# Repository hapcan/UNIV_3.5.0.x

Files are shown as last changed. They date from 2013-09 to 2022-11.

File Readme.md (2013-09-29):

UNIV 3.5.0.x
============

IR Tx/Rx MODULE - infrared transmitter/receiver

Device webpage: http://hapcan.com/devices/universal/univ_3/univ_3-5-0-x/

Hardware created in Eagle PCB Software http://www.cadsoftusa.com/

Firmware created in Microchip MPLAB http://www.microchip.com/mplabide/ in assembly language

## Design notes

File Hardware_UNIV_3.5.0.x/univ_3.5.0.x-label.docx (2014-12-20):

+5V GND IRRX IRTX ODB. I NADAJNIK PODCZERWIENI TYP UNIV 3.5.0.x S/N 0000055Bh | +5V GND IRRX IRTX INFRARED RCVR/TRNSMTR TYPE UNIV 3.5.0.x S/N 0000055Bh

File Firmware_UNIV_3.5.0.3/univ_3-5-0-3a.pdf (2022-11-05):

# INFRARED RECEIVER / TRANSMITTER FIRMWARE

# UNIV 3.5.0.3

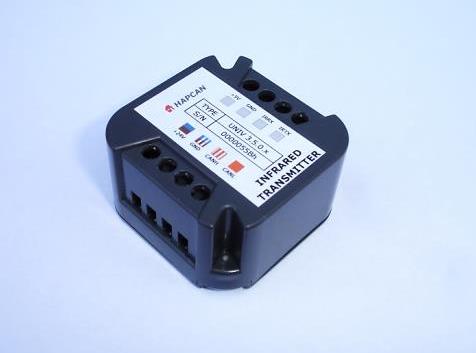
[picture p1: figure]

© 2014 hapcan.com | univ_3-5-0-3a.pdf - page 1 / 6

### 1. Features

- Firmware for Infrared Receiver/Transmitter UNIV 3.5.0.x.

- Receives and recognizes infrared codes - Sony SIRC 12 bit (32 addresses, 127 commands) – 4k codes - Sony SIRC 15 bit (256 addresses, 127 commands) – 32k codes - Sony SIRC 20 bit (8192 addresses, 127 commands) – 1M codes - Philips RC5 (32 addresses, 127 commands) – 4k codes - NEC 16 bit (256 addresses, 256 commands) – 65k codes - NEC 24 bit (65280 addresses, 256 commands) – 16M codes - Emits above codes - Learns IR codes from original remotes which have carrier frequency between 27 – 49kHz and maximum 335 bits length - Emits any IR codes with carrier frequency 18 - 500kHz - It has memory for 100 IR learnt or converted from Pronto format codes - Allows defining up to 128 CAN messages which can indirectly control the module - Transmit (42 messages) and receive (42 messages) FIFO buffers

### 2. Compatibility - Firmware for UNIV 3.5.0.x module - Firmware can be uploaded into processor with bootloader version 3.1 or

compatible.
- In current firmware version the learnt IR codes must end with a value of 00, so codes scanned in previous versions are not compatible. Please re-scan codes or edit them and the last 7F value replace with 00.

### 3. Firmware version

UNIV | 3 | . | 5 | . | 0 | . | 3

### firmware version application version application type (infrared receiver / transmitter) processor version universal processor

### 4. Communication Frames (messages)

### 4.1. Infrared Receiver frame

The module sends information of received infrared code, and another message when infrared transmission stops.

### Table 1. INFRARED RECEIVER frame – beginning of receiving the code

Frame type | Flags | Module | Group | D0 | D1 | D2 | D3 | D4 | D5 | D6 | D7
0x303 | 3 | 2 | 1 | 0 | Node Nr | Group Nr | 0xFF | 0xFF | CODE TYPE | CODE1 | CODE2 | CODE3 | 0xFF | 0xFF
0x302 | – universal module frame, relay
3 | - | - not used flag, read as “0”
2 | - | - not used flag, read as “0”
1 | - | - not used flag, read as “0”
0 | RE | - response flag, flag is equal “1” if node was requested. If flag is equal „0” it means that status of output has just changed.
Node Nr | - message sender node number
Group Nr | - message sender group number
CODE TYPE | 0x03 - received SIRC 12 bit code (32 addresses, 127
| | commands), CODE1=address, CODE2=command, CODE3=0xFF
| | 0x04 - received SIRC 15 bit code (256 addresses, 127 commands), CODE1=address, CODE2=command, CODE3=0xFF
| | 0x05 - received SIRC 20 bit code (8192 addresses, 127 commands),
| | CODE1=address MSB, CODE2=address LSB, CODE3=command 0x06- received RC5 code (32 addresses, 127 commands), CODE1=address, CODE2=command, CODE3=0xFF
| | 0x07- received NEC 16 bit code (256 addresses, 256 commands),
| | CODE1=address, CODE2=command, CODE3=0xFF 0x08 - received NEC 24 bit code, (65280 addresses, 256 commands)
| | CODE1=address MSB, CODE2=address LSB, CODE3=command

## UNIV 3.5.0.3

When transmission of infrared signal stops, the module sends another message. The difference between message at the beginning and at the end of transmission is in a D2 byte.

### Table 2. INFRARED RECEIVER frame – end of the IR transmission

Frame type | Flags | Module | Group | D0 | D1 | D2 | D3 | D4 | D5 | D6 | D7
0x303 | 0x1 | Node Nr | Group Nr | 0xFF | 0xFF | CODE TYPE +0x80 | CODE1 | CODE2 | CODE3 | 0xFF | 0xFF

### 4.2. Learning IR codes

The module enables learning and saving infrared codes into memory. Scanning should be performed in two steps: scanning the carrier frequency signal and then scanning the signal content. The current version of the HAPCAN Programmer scans only the content of the signal and assigns the default 38kHz carrier frequency.

After receiving instructions "Learn code - the carrier frequency of the transmitted IR signal from the remote controller” (control instructions) and correct receiving IR code, the module sends carrier frequency frame. If the

### module does not receive the IR code, then sends the error frame (Table 5)

### Table 3. LEARNT IR SIGNAL CARRIER FREQUENCY frame

Frame type | Flags | Module | Group | D0 | D1 | D2 | D3 | D4 | D5 | D6 | D7
0x303 | 0x1 | Node Nr | Group Nr | 0x00 | CARRIER | 0xFF | 0xFF | 0xFF | 0xFF | 0xFF | 0xFF
0x3031 | – universal module, infrared receiver frame
Node Nr | - message sender node number
Group Nr | - message sender group number
0x00 | - frame data type (0x00 – IR carrier frequency frame)
CARRIER | - received frequency codded: f = 4608/(CARRIER+1) [kHz]

After receiving instructions "Learn code - the body of transmitted IR signal from the remote controller” (control instructions) and correct receiving IR code, the module sends 96 frames containing IR signal body. If there is any

### problem with code learning, the module sends error frame (Table 5)

### Table 4. LEARNT IR SIGNAL CODE frames

Frame type | Flags | Module | Group | D0 | D1 | D2 | D3 | D4 | D5 | D6 | D7
0x303 | 0x1 | Node Nr | Group Nr | FRAME No | CODE0 | CODE1 | CODE2 | CODE3 | CODE4 | CODE5 | CODE6
0x3031 | – universal module, infrared receiver frame
Node Nr | - message sender node number
Group Nr | - message sender group number
FRAME No | - number of frame with IR code (1-96)
CODE0 | - IR signal carrier frequency taken from IR signal carrier frequency frame (Table 1)
CODE1-672 | - data of received IR (671 bytes sent in 96 frames)
Bit <7> of each byte defines if this is IR burst (bit <7> = „1”) or space (bit <7> = „0”) in IR code
The length of the burst or space is equal: 40us * byte_value (7 bit value -without 7th bit)

If there is any problem with code learning, the module sends error frame.

### Table 5. LEARNT CODE ERROR frame

Frame type | Flags | Module | Group | D0 | D1 | D2 | D3 | D4 | D5 | D6 | D7
0x303 | 0x1 | Node Nr | Group Nr | 0xF0 | 0xFF | 0xFF | 0xFF | 0xFF | 0xFF | 0xFF | 0xFF
0x3031 | – universal module, infrared receiver frame
Node Nr | - message sender node number
Group Nr

0xF0 - frame data type (0xF0 – learnt code error frame)

### 4.3. Status request

Module doesn’t respond to status request.

### 4.4. Uptime request

Table 6. UPTIME REQUEST (0x113).
Frame type | Flags | Module | Group | D0 | D1 | D2 | D3 | D4 | D5 | D6 | D7
0x113 | 0x0 | COMP ID1 | COMP ID2 | 0xXX | 0xXX | Node Nr | Group Nr | 0xXX | 0xXX | 0xXX | 0xXX
0x1130 | – UPTIME REQUEST frame
COMP ID1 | - computer identifier (must be unique on the network)
COMP ID2 | - computer identifier (must be unique on the network)
Node Nr | - node number of requested module
Group Nr | - group number of requested module
0xXX | - inessential data

Table 7. Response to UPTIME REQUEST (0x113).
Frame type | Flags | Module | Group | D0 | D1 | D2 | D3 | D4 | D5 | D6 | D7
0x113 | 0x1 | Node Nr | Group Nr | 0xFF | 0xFF | 0xFF | 0xFF | UPTIME3 | UPTIME2 | UPTIME1 | UPTIME0
0x1131 | – Response to UPTIME REQUEST frame
Node Nr | - node number on the network
Group Nr | - group number of the node on the network
UPTIME | - (UPTIME3*256³+UPTIME2*256²+UPTIME1*256¹+UPTIME3*256⁰
) in seconds

### 4.5. Health check request

Table 8. HEALTH CHECK - STATUS REQUEST (0x115).
Frame type | Flags | Module | Group | D0 | D1 | D2 | D3 | D4 | D5 | D6 | D7
0x115 | 0x0 | COMP ID1 | COMP ID2 | 0x01 | 0xXX | Node Nr | Group Nr | 0xXX | 0xXX | 0xXX | 0xXX
0x1150 | – HEALTH CHECK REQUEST frame
COMP ID1 | - computer identifier (must be unique on the network)
COMP ID2 | - computer identifier (must be unique on the network)
0x01 | - status request
Node Nr | - node number of requested module
Group Nr | - group number of requested module
0xXX | - inessential data

As response the module will send two frames (Table 7).

Table 9. Response to HEALTH CHECK - STATUS REQUEST (0x115).
Frame type | Flags | Module | Group | D0 | D1 | D2 | D3 | D4 | D5 | D6 | D7
0x115 | 0x1 | Node Nr | Group Nr | 0x01 | RXCNT | TXCNT | RXCNTMX | TXCNTMX | CANINTCNT | RXERRCNT | TXERRCNT
0x1151 | – Response to HEALTH CHECK REQUEST frame
Node Nr | - node number on the network
Group Nr | - group number of the node on the network
0x01 | - frame 1 (current values)
RXCNT | - current level of receive FIFO buffer
TXCNT | - current level of transmit FIFO buffer
RXCNTMX | - maximum level of receive FIFO buffer since power up
TXCNTMX | - maximum level of transmit FIFO buffer since power up
CANINTCNT | - number of CAN interface restarts since power up
RXERRCNT | - current receive errors register
TXERRCNT | - current transmit errors register

Frame type | Flags | Module | Group | D0 | D1 | D2 | D3 | D4 | D5 | D6 | D7
0x115 | 0x1 | Node Nr | Group Nr | 0x02 | 0xFF | 0xFF | RXCNTMXE | TXCNTMXE | CANINTCNTE | RXERRCNTE | TXERRCNTE
0x1151 | – Response to HEALTH CHECK REQUEST frame
Node Nr | - node number on the network
Group Nr | - group number of the node on the network
0x02 | - frame 2 (maximum values saved in eeprom memory)
RXCNTMXE | - maximum ever level of receive FIFO buffer
TXCNTMXE | - maximum ever level of transmit FIFO buffer
CANINTCNTE | - maximum ever number of CAN interface restarts
RXERRCNTE | - maximum ever receive errors
TXERRCNTE | - maximum ever transmit errors

To clear maximum values saved in eeprom memory the frame shown in Table 8 must be sent. There is no response to this message.

Table 10. HEALTH CHECK - CLEAR REQUEST (0x115).
Frame type | Flags | Module | Group | D0 | D1 | D2 | D3 | D4 | D5 | D6 | D7
0x115 | 0x0 | COMP ID1 | COMP ID2 | 0x02 | 0xXX | Node Nr | Group Nr | 0xXX | 0xXX | 0xXX | 0xXX
0x1150 | – HEALTH CHECK REQUEST frame
COMP ID1 | - computer identifier (must be unique on the network)
COMP ID2 | - computer identifier (must be unique on the network)
0x02 | - clear request
Node Nr | - node number of requested module
Group Nr | - group number of requested module
0xXX | - inessential data

### 5. Module control The module can be controlled directly from PC, or indirectly by other modules

### 5.1. Control instruction

The table below shows all instructions, which can be executed by the module. Some of them can be executed only with direct control and other with indirect control (through other modules).

### Table 11. Module instructions

Instruction

Instruction Codding

Note

Control

INSTR1 | INSTR2 | INSTR3 | INSTR4 | INSTR5 | INSTR6 | INSTR7 | INSTR8

Direct

Indirect

LEARN CODE (carrier frequency) | 0x00 | 0x00 | 0xXX | 0xXX | 0xXX | 0xXX | 0xXX | 0xXX | Module waits about 6s for IR signal. When signal is properly received, the module sends CAN message (Table 3) containing carrier frequency. (Needs IR diode connected to the module) | √
LEARN CODE (code body) | 0x00 | 0x01 | 0xXX | 0xXX | 0xXX | 0xXX | 0xXX | 0xXX | Module waits about 6s for IR signal. When signal is properly received, the module send CAN messages (Table 4) containing learnt IR code. (Needs IR receiver TSOP4838 connected to the module) | √
SEND LEARNT CODE | 0x01 | CODE No | 0xXX | 0xXX | 0xXX | 0xXX | 0xXX | 0xXX | Emits IR code which is saved in module memory. The number of the code 1-100 (0x01-0x64) must be given in INTR2 byte. | √ | √
SEND RECEIVED CODE | 0x02 | 0xXX | 0xXX | 0xXX | 0xXX | 0xXX | 0xXX | 0xXX | Sends code which was received by other IR receiver and passed over the bus. IR receivers, as control sources, can be defined when linking devices | | √
SEND SONY SIRC 12bit | 0x03 | ADR | COMM | 0xXX | 0xXX | 0xXX | 0xXX | 0xXX | Sends SIRC 12 bit code (32 addresses, 127 commands). The code address must be given in NSTR2 byte, and command in INSTR3 byte | √ | √
SEND SONY SIRC 15bit | 0x04 | ADR | COMM | 0xXX | 0xXX | 0xXX | 0xXX | 0xXX | Sends SIRC 15 bit code (256 addresses, 127 commands). The code address must be given in NSTR2 byte, and command in INSTR3 byte | √ | √
SEND SONY SIRC 20bit | 0x05 | ADRH | ADRL | COMM | 0xXX | 0xXX | 0xXX | 0xXX | Sends SIRC 20 bit code (8192 addresses, 127 commands). The code MSB address must be given in INSTR2 byte, LSB addres in INSTR2 byte and command in INSTR4 | √ | √
SEND PHILIPS RC5 | 0x06 | ADR | COMM | 0xXX | 0xXX | 0xXX | 0xXX | 0xXX | Sends Philips RC5 code (32 addresses, 127 commands). The code address must be given in INSTR2 byte, and command in INSTR3 byte | √ | √
SEND NEC 16bit | 0x07 | ADR | COMM | 0xXX | 0xXX | 0xXX | 0xXX | 0xXX | Sends NEC 16 bit code (256 addresses, 256 commands). The code address must be given in INSTR2 byte, and command in INSTR3 byte | √ | √
SEND NEC 24bit | 0x08 | ADRH | ADRL | COMM | 0xXX | 0xXX | 0xXX | 0xXX | Sends NEC 24 bit code (65280 addresses, 127 commands). The code MSB address must be given in INSTR2 byte, LSB address in INSTR2 byte and command in INSTR4 | √ | √
ENABLE BOX | 0xDD | BoxX | BoxY | 0xXX | 0xXX | 0xXX | 0xXX | 0xXX | It enables chosen boxes – these boxes will be compared with next received message from the bus. | | √

DISABLE BOX | 0xDE | BoxX | BoxY | 0xXX | 0xXX | 0xXX | 0xXX | 0xXX | It disables chosen boxes – these boxes will be passed when next message arrives from the bus. | √
TOGGLE BOX | 0xDF | BoxX | BoxY | 0xXX | 0xXX | 0xXX | 0xXX | 0xXX | It toggles boxes – enables when they are disabled and vice versa | √

0xXX – inessential data

BoxX | Note
0x00 | - from Box 1
0x01 | - from Box 2
…
0x7F | - from Box 128
BoxY | Note
0x00 | + 0 -(and not anyone else)
0x01 | + 1 -( and 1 following)
…
0x7F | +127 -( and 127 following)

### 5.2. Direct control

It is possible to control module by sending DIRECT CONTROL message. The message contains instruction, which will be executed by the module.

Table 12. DIRECT CONTROL frame (0x10A).
Frame type | Flags | Module | Group | D0 | D1 | D2 | D3 | D4 | D5 | D6 | D7
0x10A | 0x0 | COMP ID1 | COMP ID2 | INSTR1 | INSTR2 | Node Nr | Group Nr | INSTR3 | INSTR4 | INSTR5 | INSTR6
0x10A | – DIRECT CONTROL frame
COMP ID1 | - computer identifier (must be unique on the network)
COMP ID2 | - computer identifier (must be unique on the network)
Node Nr | - node number of requested module
Group Nr | - group number of requested module
INSTR1-6 | - instruction to be executed (6 bytes)

### 5.3. Indirect control

Indirect control means that module will react to messages sent by other modules on the network. It depends on configuration programmed into the module boxes (memory cells).
This firmware has feature to set simple conditions of executing instruction. To do so, you can use blocking instruction (0xDD – 0xDF) shown in the table 11. The HAPCAN Programmer simplifies configuration process.

### 6. Configuration Parameters that can be configured with this firmware:

- Module identifier (module number and group number);
- Module description (16 chars);

### - Learnt IR codes

- Text notes;
- Linking device with other modules (indirect control of module). Configuration process can be done using HAPCAN Programmer.

### 6.1. Module identifier

Every module on the network must have unique identifier. The identifier is made of two bytes, module number (1 byte) and group number (1 byte). Identifier of the Ethernet Interface can be changed in HAPCAN Programmer in software settings.

### 6.2. Module description

Every module can have 16 char description, which makes easier for user (programmer) to distinguish nodes.

### 6.3. Learnt IR code

The firmware has 100 memory cells to store up to 100 learnt or manually entered (in Pronto format) infrared codes. Some IR codes might be longer and they can be saved in max 3 memory cells.

6.4. Text notes.
Up to 1024 characters can be written into processor’s memory.

### 6.5. Linking devices

The module has 128 memory cells (boxes). Each box can contain information about message sent by other node, and instruction which will be executed when that message is received.

### 7. License

HAPCAN Home Automation Project firmware, Copyright (C) 2014 hapcan.com

This program is free firmware: you can redistribute it and/or modify it under the terms of the GNU General Public License as published by the Free Software Foundation, either version 3 of the License, or (at your option) any later version.

This firmware is distributed in the hope that it will be useful, but WITHOUT ANY WARRANTY; without even the implied warranty of MERCHANTABILITY or FITNESS FOR A PARTICULAR PURPOSE. See the GNU General Public License for more details.

You should have received a copy of the GNU General Public License along with this firmware. If not, see http://www.gnu.org/licenses/gpl-3.0.html.

### 8. Document version

File | Note | Date
univ_3-5-0-3a.pdf | Original version | April 2014

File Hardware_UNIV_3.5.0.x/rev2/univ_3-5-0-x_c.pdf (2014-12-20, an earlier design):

## INFRARED RECEIVER / TRANSMITTER

# UNIV 3.5.0.x

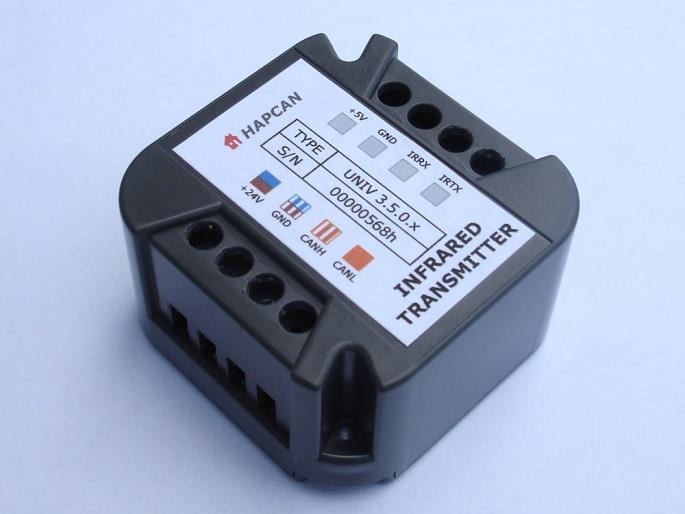
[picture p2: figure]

© 2013 hapcan.com | univ_3-5-0-x_c.pdf - page 1 / 5

### 1. Features

- The module to control AV devices
- Can emits IR signals with carrier frequency up to 500kHz
- Can learn IR codes from original remotes
- Operation voltage 10-24V
- Maximum current consumption 20mA
- For deep back box mounting.
- Dimensions 44x44x25 mm
- Operating of module depends on firmware uploaded into it.
- Schematic and PCB design can be downloaded from hapcan.com site

### 2. Application version

UNIV | 3 | . | 5 | . | 0 | . | x
firmware version
application version
application type (infrared receiver / transmitter) processor version
universal processor

### 3. Technical data

Bus side
Parameter | Symbol | Value | Unit
Power supply voltage | Us | 10-24V | V
Current consumption | Is | 12 | mA
Maximum current consumption | Ismax | 20 | mA
Bus connector type | 4 terminal blocks

IR emitter and receiver side
Parameter | Unit
Connector type | 4 terminal blocks
IR receiver | TSOP4838 Vishay
IR emitter | Any IR LED 940nm

### 4. Hardware

### 4.1. Wiring

HAPCAN bus wiring
+24V | - brown & blue | -
GND | - white/brow & white/blue | -
CANH | - white/orange | -
CANL | - orange | -

Note that if module is first or last on the bus, resistor 120ohm must be connected between pins CANH and CANL.

Figure 1. Wiring diagram

+24V | GND | CANH | CANL

1 2 3

OUT

GND
Vs
3 | 2 | 1

TSOP 4838

+5V GND IRRX IRTX

TSOP 4838
IRED

## UNIV 3.5.0.x

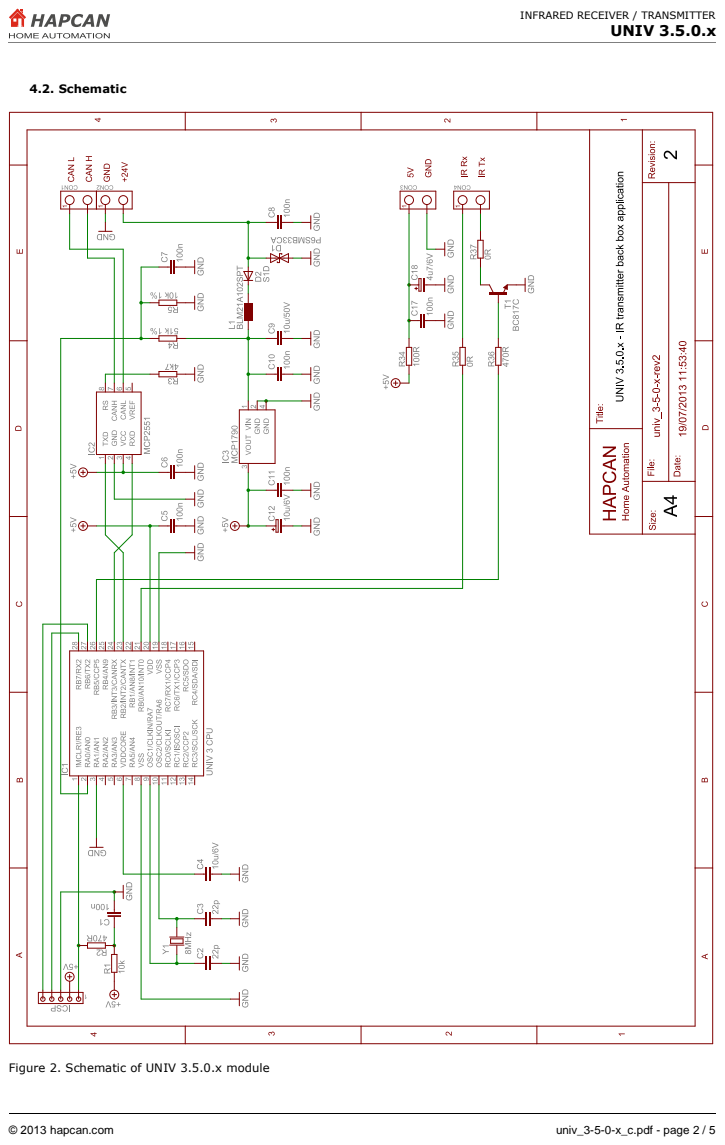
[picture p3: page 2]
4.2. Schematic

Figure 2. Schematic of UNIV 3.5.0.x module

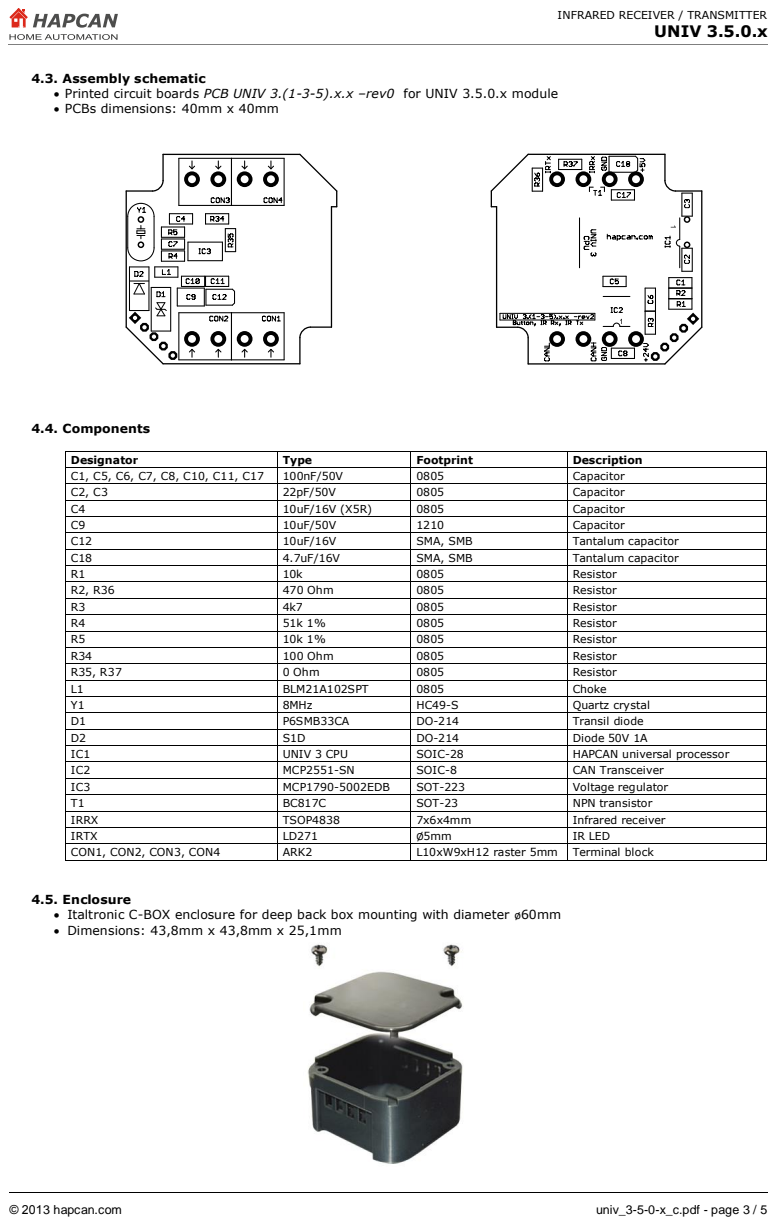
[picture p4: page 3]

4.3. Assembly schematic
• Printed circuit boards PCB UNIV 3.(1-3-5).x.x –rev0 for UNIV 3.5.0.x module
• PCBs dimensions: 40mm x 40mm

Designator | Type | Footprint | Description
C1, C5, C6, C7, C8, C10, C11, C17 | 100nF/50V | 0805 | Capacitor
C2, C3 | 22pF/50V | 0805 | Capacitor
C4 | 10uF/16V (X5R) | 0805 | Capacitor
C9 | 10uF/50V | 1210 | Capacitor
C12 | 10uF/16V | SMA, SMB | Tantalum capacitor
C18 | 4.7uF/16V | SMA, SMB | Tantalum capacitor
R1 | 10k | 0805 | Resistor
R2, R36 | 470 Ohm | 0805 | Resistor
R3 | 4k7 | 0805 | Resistor
R4 | 51k 1% | 0805 | Resistor
R5 | 10k 1% | 0805 | Resistor
R34 | 100 Ohm | 0805 | Resistor
R35, R37 | 0 Ohm | 0805 | Resistor
L1 | BLM21A102SPT | 0805 | Choke
Y1 | 8MHz | HC49-S | Quartz crystal
D1 | P6SMB33CA | DO-214 | Transil diode
D2 | S1D | DO-214 | Diode 50V 1A
IC1 | UNIV 3 CPU | SOIC-28 | HAPCAN universal processor
IC2 | MCP2551-SN | SOIC-8 | CAN Transceiver
IC3 | MCP1790-5002EDB | SOT-223 | Voltage regulator
T1 | BC817C | SOT-23 | NPN transistor
IRRX | TSOP4838 | 7x6x4mm | Infrared receiver
IRTX | LD271 | Ø5mm | IR LED
CON1, CON2, CON3, CON4 | ARK2 | L10xW9xH12 raster 5mm | Terminal block

4.5. Enclosure
• Italtronic C-BOX enclosure for deep back box mounting with diameter ø60mm
• Dimensions: 43,8mm x 43,8mm x 25,1mm

### 4.6. Dimensions

### 4.7. Labels

Editable labels version is available on hapcan.com site.

+5V | GND | IRRX | IRTX

INFRARED

RCVR/TRNSMTR

TYPE | UNIV 3.5.0.x
S/N | 0000055Bh
+24V | GND | CANH | CANL

### 5. Commissioning

### 5.1. CPU voltage measurement

After verifying the correctness and quality of the soldering, the bus voltage should be connected while measuring the processor voltage. To do this, connect a voltmeter to pins 2 and 3 of the ICSP connector. Processor supply voltage should be about 5V.

Figure 3. CPU voltage measurement

### 5.2. Checking the CPU clock

Proper operation of the CPU can be checked by temporarily connecting the LED to pins 3 and 5 of the ICSP connector. When device is powered, the LED should light up four times in the sequence 1 second on - 1 second off
- 1 second on. The LED lights up only once for 50ms, if the processor is in programming mode.

Figure 4. Checking the CPU clock

### 5.3. Firmware uploading

The device requires a firmware uploading for proper operation. It can be done with HAPCAN Programmer software. Both, firmware and HAPCAN Programmer can be downloaded from hapcan.com website.

43.8

43.8

25.1

1
V

### ICSP

1

### ICSP

470 Ohm

### 6. License

HAPCAN Home Automation Project hardware, Copyright (C) 2013 hapcan.com

This device is free hardware: you can redistribute it and/or modify it under the terms of the GNU General Public License as published by the Free Software Foundation, either version 3 of the License, or (at your option) any later version.

This hardware is distributed in the hope that it will be useful, but WITHOUT ANY WARRANTY; without even the implied warranty of MERCHANTABILITY or FITNESS FOR A PARTICULAR PURPOSE. See the GNU General Public License for more details.

You should have received a copy of the GNU General Public License along with this documentation. If not, see http://www.gnu.org/licenses/gpl-3.0.html.

### 7. Document version

File | Description | Date
univ_3-5-0-x_a.pdf | Original version | July 2013
univ_3-5-0-x_b.pdf | Updated with PCB UNIV 3.(1-3-5).x.x –rev2 | July 2013
univ_3-5-0-x_c.pdf | The module is IR receiver and transmitter | October 2013

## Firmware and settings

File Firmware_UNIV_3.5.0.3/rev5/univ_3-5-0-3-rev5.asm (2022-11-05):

;==============================================================================
;   MIT License
;
;   Copyright (c) 2022 HAPCAN Home Automation Project (http://hapcan.com)
;
;   Permission is hereby granted, free of charge, to any person obtaining a copy
;   of this software and associated documentation files (the "Software"), to deal
;   in the Software without restriction, including without limitation the rights
;   to use, copy, modify, merge, publish, distribute, sublicense, and/or sell
;   copies of the Software, and to permit persons to whom the Software is
;   furnished to do so, subject to the following conditions:
;
;   The above copyright notice and this permission notice shall be included in all
;   copies or substantial portions of the Software.
;
;   THE SOFTWARE IS PROVIDED "AS IS", WITHOUT WARRANTY OF ANY KIND, EXPRESS OR
;   IMPLIED, INCLUDING BUT NOT LIMITED TO THE WARRANTIES OF MERCHANTABILITY,
;   FITNESS FOR A PARTICULAR PURPOSE AND NONINFRINGEMENT. IN NO EVENT SHALL THE
;   AUTHORS OR COPYRIGHT HOLDERS BE LIABLE FOR ANY CLAIM, DAMAGES OR OTHER
;   LIABILITY, WHETHER IN AN ACTION OF CONTRACT, TORT OR OTHERWISE, ARISING FROM,
;   OUT OF OR IN CONNECTION WITH THE SOFTWARE OR THE USE OR OTHER DEALINGS IN THE
;   SOFTWARE.
;==============================================================================
;   Filename:              univ_3-5-0-3.asm
;   Associated diagram:    univ_3-5-0-x.sch
;   Author:                Jacek Siwilo                          
;   Note:                  Infrared transmitter /receiver
;==============================================================================
;   Revision History
;   Rev:  Date:     Details:
;   0     03.2014   Original version
;   1     10.2014   Received IR code is matched against boxes
;   2     11.2014   Corrections (line 568)
;   3     08.2017   Updated with univ3-routines-rev7.inc
;   4     01.2018   RC5 message is transmitted once
;   5     11.2022   Updated with univ3-routines-rev9.inc
;==============================================================================
;===  FIRMWARE DEFINITIONS  =================================================== 
;==============================================================================
    #define    ATYPE    .5                            ;application type [0-255]
    #define    AVERS    .0                         ;application version [0-255]
    #define    FVERS    .3                            ;firmware version [0-255]

    #define    FREV     .5                         ;firmware revision [0-65536]
;==============================================================================
;===  NEEDED FILES  ===========================================================
;==============================================================================
    LIST P=18F26K80                              ;directive to define processor
    #include <P18F26K80.INC>           ;processor specific variable definitions
    #include "univ_3-5-0-3-rev5.inc"                         ;project variables

INCLUDEDFILES   code  
    #include "univ3-routines-rev9.inc"                     ;UNIV 3 CPU routines
    #include "univ3-IR_LIR-rev2.inc"                        ;LIR infrared codes
    #include "univ3-IR_Sony_SIRC-rev0.inc"                 ;Sony infrared codes
    #include "univ3-IR_Philips_RC5-rev1.inc"            ;Philips infrared codes
    #include "univ3-IR_NEC-rev0.inc"                        ;NEC infrared codes

;==============================================================================
;===  FIRMWARE CHECKSUM  ======================================================
;==============================================================================
FIRMCHKSM   code    0x001000
    DB      0x61, 0x5C, 0x24, 0xFF, 0xFF, 0xFF, 0xFF, 0xFF            
;==============================================================================
;===  FIRMWARE ID  ============================================================
;==============================================================================
FIRMID      code    0x001010
    DB      0x30, 0x00, 0x03,ATYPE,AVERS,FVERS,FREV>>8,FREV
;            |     |     |     |     |     |     |_____|_____ firmware revision
;            |     |     |     |     |     |__________________ firmware version
;            |     |     |     |     |_____________________ application version
;            |     |     |     |______________________________ application type
;            |     |     |________________________________ hardware version '3'
;            |_____|______________________________________ hardware type 'UNIV'
;==============================================================================
;===  MOVED VECTORS  ==========================================================
;==============================================================================
;PROGRAM RESET VECTOR
FIRMRESET   code    0x001020
        goto    Main
;PROGRAM HIGH PRIORITY INTERRUPT VECTOR
FIRMHIGHINT code    0x001030
        call    HighInterrupt
        retfie
;PROGRAM LOW PRIORITY INTERRUPT VECTOR
FIRMLOWINT  code    0x001040
        call    LowInterrupt
        retfie

;==============================================================================
;===  FIRMWARE STARTS  ========================================================
;==============================================================================
FIRMSTART   code    0x001050
;------------------------------------------------------------------------------
;---  LOW PRIORITY INTERRUPT  -------------------------------------------------
;------------------------------------------------------------------------------
LowInterrupt
        movff   STATUS,STATUS_LOW           ;save STATUS register
        movff   WREG,WREG_LOW               ;save working register
        movff   BSR,BSR_LOW                 ;save BSR register
        movff   FSR0L,FSR0L_LOW             ;save other registers used in high int
        movff   FSR0H,FSR0H_LOW
        movff   FSR1L,FSR1L_LOW
        movff   FSR1H,FSR1H_LOW

    ;main firmware ready flag
        banksel FIRMREADY
        btfss   FIRMREADY,0
        bra     ExitLowInterrupt            ;main firmware is not ready yet
    ;CAN buffer
        banksel CANFULL
        btfsc   CANFULL,0                   ;check if CAN received anything
        call    CANInterrupt                ;proceed with CAN interrupt

ExitLowInterrupt
        movff   BSR_LOW,BSR                 ;restore BSR register
        movff   WREG_LOW,WREG               ;restore working register
        movff   STATUS_LOW,STATUS           ;restore STATUS register
        movff   FSR0L_LOW,FSR0L             ;restore other registers used in high int
        movff   FSR0H_LOW,FSR0H
        movff   FSR1L_LOW,FSR1L
        movff   FSR1H_LOW,FSR1H
    return
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

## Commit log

2013-09-25 hardware revision 2
    [pcb_univ_3-(1-3-5)-x-x-rev2.brd, pcb_univ_3-(1-3-5)-x-x-rev2.sch, univ_3-5-0-x-rev2.sch]
2013-09-25 firmware revision 0
    [IR_LIR_calculations.xlsx]
2014-11-11 firmware UNIV 3.5.0.3 revision 2
    [IR_LIR_calculations.xlsx, univ_3-5-0-3-rev2-memory.xlsx]
2014-12-07 hardware UNIV 3.5.0.x revision 2
    [pcb_univ_3-(1-3-5)-x-x-rev2.brd, pcb_univ_3-(1-3-5)-x-x-rev2.sch, univ_3-5-0-x-rev2.sch]
2014-12-20 hardware UNIV 3.5.0.x revision 4
    [pcb_univ_3-(1-3-5)-x-x-rev4.brd, pcb_univ_3-(1-3-5)-x-x-rev4.sch, univ_3-5-0-x-rev4.sch]
2017-08-19 firmware UNIV 3.5.0.3 revision 3
    [IR_LIR_calculations.xlsx, univ_3-5-0-3-rev3-memory.xlsx]
2022-11-05 firmware UNIV 3.5.0.3 revision 5
    [IR_LIR_calculations.xlsx, univ_3-5-0-3-rev5-memory.xlsx]
